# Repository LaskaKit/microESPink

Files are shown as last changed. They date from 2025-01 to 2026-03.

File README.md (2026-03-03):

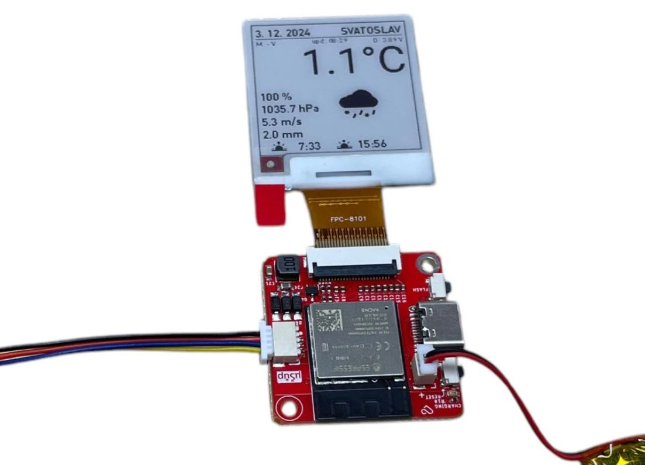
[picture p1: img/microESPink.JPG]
MicroESPink

# microESPink - micro version of ESPink - versatile and low power board with ESP32-S3 for ePaper/eInk

The MicroESPink thus complements the separate board we also offer, the [very low power and versatile ESPink](https://www.laskakit.cz/laskakit-espink-esp32-e-paper-pcb-antenna/?variantId=12419). The MicroESPink is smaller and it is also possible to connect other ePaper displays.</br>

The MicroESPink is based on the ESP32-S3 instead of the ESP32 (larger ESPink). We saved space by removing unused GPIO pins on the edge of the ESPink board, SPI usup connector etc.</br>

If you prefer a ready-to-use kit with glued ePaper, then we offer [Laskakit ESPink-Shelf-2.9 ESP32 e-Paper](https://www.laskakit.cz/laskakit-espink-shelf-2-9-esp32-e-paper/?variantId=14193, [LaskaKit ESPink-4.2 ESP32 e-Paper](https://www.laskakit.cz/laskakit-espink-42-esp32-e-paper-pcb-antenna/?variantId=13538) and [LaskaKit ESPink-Shelf-2.13 ESP32 e-Paper](https://www.laskakit.cz/laskakit-espink-shelf-213-esp32-e-paper/).</br>

The MicroESPink is based on the ESP32-S3 chip, which has support for both Wi-Fi 4 and Bluetooth 5. The board includes a 1mm pitch JST-SH battery connector. The cable for this connector can be found [in our e-shop](https://www.laskakit.cz/jst-sh-2-1-0mm-2pin-konektor-s-kabelem-10cm--oboustranny/), and the ready-made batteries with this connector are [200mAh](https://www.laskakit.cz/geb-lipol-baterie-302040-200mah-3-7v-jst-sh-2-0/) and [400mAh](https://www.laskakit.cz/geb-lipol-baterie-303048-400mah-3-7v-jst-sh-2-0/).</br>

The charging current is set by resistor R11.</br>

MicroESPink is equipped with our[universal I2C uŠup port connector](https://blog.laskakit.cz/predstavujeme-univerzalni-konektor-pro-propojeni-modulu-a-cidel-%CE%BCsup/) to which you can connect various sensors - [SHT40 (temperature, humidity)](https://www.laskakit.cz/laskakit-sht40-senzor-teploty-a-vlhkosti-vzduchu/), [BME280 (pressure, temperature, humidity)](https://www.laskakit.cz/arduino-senzor-tlaku--teploty-a-vlhkosti-bme280/), [SCD41 (CO2, temperature, humidity)](https://www.laskakit.cz/laskakit-scd41-senzor-co2--teploty-a-vlhkosti-vzduchu/), [BH1750 (lighting)](https://www.laskakit.cz/laskakit-bh1750-snimac-intenzity-osvetleni/), [APDS-9960 (gesture sensor)](https://www.laskakit.cz/laskakit-apds-9960-senzor-priblizeni-a-gest/) and many other sensors. </br>
Our I2C ushup connector is compatible with Adafruit Stemma and Qwiik from Sparkfun.</br>

The board supports the popular Živý Obraz project which greatly simplifies the use of ePaper displays to display photos, (google, outlook, apple) calendar, weather station readings, weather forecasts and much more. No need to write code, just upload the correct type of ePaper and board through the web environment and follow the procedure described [in the documentation](https://wiki.zivyobraz.eu/).</br>
[You upload the program through the webpage](https://zivyobraz.eu/?page=instalace) on this page and just select the <b>LaskaKit ESPink 3.x board</b> and the <b>correct ePaper type according to the one you ordered</b>.</br>

If you want to write your own program, go ahead :-)</br>
On our github you can find a [schematic](https://github.com/LaskaKit/microESPink/tree/main/HW) of the board and we have not forgotten the [sample codes](https://github.com/LaskaKit/microESPink/tree/main/SW), which should make programming and working with our microESPink much easier.</br>
</br>
Some technical information:</br>
The board consumption is around 16uA without connected peripherals.</br>
IO pins for I2C uŠup bus are used - SDA IO42 and SCL IO2.</br>
Power supply for external I2C sensors (uŠup), Fuel Gauge MAX17048 and ePaper is switched via GPIO pin 47. Active in HIGH.</br>
Battery status is monitored by the Fuel Gauge MAX17048 sensor connected to the same I2C bus. Its ALERT output is connected to GPIO pin 9.</br>
The MicroESPink has two pre-made solder bridges to adjust the driver settings on the board - see the schematic for a description of the settings for the ePapers.</br>
Both battery charging and board programming is done via USB-C.</br>
The board needs to be switched to recording mode, this is done by the following procedure: connect USB-C, press and hold the FLASH button, press and release the RESET button, then release the FLASH button.</br>
</br>
## The microESPink is available on https://www.laskakit.cz/laskakit-microespink-esp32-s3-mini-e-paper/?variantId=17078

| Display | JP1 | JP2 |
| --- | --- | --- |
| GDEWO0154T8D | ON | ON |
| GDEY0154D67 | OFF | ON |
| GDEY0154Z90 | OFF | OFF |
| GDEY0213B74 | OFF | ON |
| GDEW0213TS5D | ON | ON |
| GDEY027T91 | OFF | ON |
| GDEWO029TS5D | ON | OFF |
| GDEY029T94 | OFF | ON |
| GDEYO29F51H | OFF | OFF |
| GDEY029T71H | OFF | OFF |
| GDEY042T81 | OFF | ON |
| GDEQ042Z21 | ON | OFF |
| GDEY042Z798 | OFF | OFF |
| GDEQ0426T82 | OFF | ON |
| GDEPO565D90 | ON | OFF |
| GDEQ0583T31 | ON | OFF |
| GDEQ0583Z31 | ON | OFF |
| GDEYO7ST7 | ON | OFF |
| GDEY075Z08 | ON | OFF |
| GDEM102T91 | OFF | ON |
| GDEM102Z91 | ON | OFF |
| GDEM1085T51 | OFF | OFF |
| GDEY116Z91 | OFF | ON |
| GDEY116T91 | OFF | ON |
| GDEY116F51 | OFF | OFF |
| GDEM133Z91 | OFF | ON |
| GDEM133T91 | OFF | ON |

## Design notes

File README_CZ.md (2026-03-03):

MicroESPink

# microESPink - mikro verze desky ESPink - univerzální a velmi úsporná deska s ESP32-S3 pro ePaper

MicroESPink tak doplňuje samostatnou desku, kterou máme také v nabídce [velmi úspornou a univerzální ESPink](https://www.laskakit.cz/laskakit-espink-esp32-e-paper-pcb-antenna/?variantId=12419). MicroESPink je menší a je také možné připojit jiné ePaper displeje. </br>

MicroESPink je založen na ESP32-S3 namísto ESP32 (větší ESPink). Místo jsme ušetřili odebráním nepoužitých GPIO pinů na okraji desky ESPink, SPI uŠup konektoru atp.</br>

Pokud preferuješ už hotový kit s přilepeným ePaper, pak máme v nabídce [Laskakit ESPink-Shelf-2.9 ESP32 e-Paper](https://www.laskakit.cz/laskakit-espink-shelf-2-9-esp32-e-paper/?variantId=14193), [LaskaKit ESPink-4.2 ESP32 e-Paper](https://www.laskakit.cz/laskakit-espink-42-esp32-e-paper-pcb-antenna/?variantId=13538) a [LaskaKit ESPink-Shelf-2.13 ESP32 e-Paper](https://www.laskakit.cz/laskakit-espink-shelf-213-esp32-e-paper/).</br>

MicroESPink je založený na čipu ESP32-S3, který má podporu jak Wi-Fi 4, tak i Bluetooth 5.
Deska obsahuje konektor pro baterii JST-SH s roztečí 1mm. Kabel pro tento konektor [najdeš v našem e-shopu](https://www.laskakit.cz/jst-sh-2-1-0mm-2pin-konektor-s-kabelem-10cm--oboustranny/), už hotové baterie s tímto konektorem jsou pak [200mAh](https://www.laskakit.cz/geb-lipol-baterie-302040-200mah-3-7v-jst-sh-2-0/) a [400mAh](https://www.laskakit.cz/geb-lipol-baterie-303048-400mah-3-7v-jst-sh-2-0/).

Nabíjecí proud je nastaven rezistorem R11.

MicroESPink má osazený [náš univerzální I2C uŠup konektor](https://blog.laskakit.cz/predstavujeme-univerzalni-konektor-pro-propojeni-modulu-a-cidel-%CE%BCsup/) ke kterým můžeš připojit nejrůznější čidla - [SHT40 (teplota, vlhkost)](https://www.laskakit.cz/laskakit-sht40-senzor-teploty-a-vlhkosti-vzduchu/), [BME280 (tlak, teplota, vlhkost)](https://www.laskakit.cz/arduino-senzor-tlaku--teploty-a-vlhkosti-bme280/), [SCD41 (CO2, teplota, vlhkost)](https://www.laskakit.cz/laskakit-scd41-senzor-co2--teploty-a-vlhkosti-vzduchu/), [BH1750 (osvětlení)](https://www.laskakit.cz/laskakit-bh1750-snimac-intenzity-osvetleni/), [APDS-9960 (senzor gest)](https://www.laskakit.cz/laskakit-apds-9960-senzor-priblizeni-a-gest/) a spoustu další senzorů. Náš I2C uŠup konektor je kompatibilní s Adafruit Stemma a Qwiik od Sparkfun.</br>
</br>
Deska podporuje populární projekt Živý Obraz, který výrazně zjednodušuje použití ePaper displeje k zobrazení fotografií, (google, outlook, apple) kalendáře, kurzů, hodnot z meteostanic, předpovědi počasí a mnoho dalšího. Není nutné psát kód, stačí nahrát správný typ ePaper a desky skrze webové prostředí a dodržet postup popsaný v [dokumentaci](https://wiki.zivyobraz.eu/).</br>
Program nahraješ [přes webové prostředí na této stránce](https://zivyobraz.eu/?page=instalace) a stačí zvolit desku <b>LaskaKit ESPink 3.x</b> a <b>správný typ ePaperu podle toho, který sis objednal</b>. </br>
</br>
Pokud si chceš napsat vlastní program, tak do toho :-)</br>
Na našem github máš [schéma desky](https://github.com/LaskaKit/microESPink/tree/main/HW) a nezapomněli jsme ani na [vzorové kódy](https://github.com/LaskaKit/microESPink/tree/main/SW), které by ti značně měly usnadnit programování a práci s naším microESPink. </br>
</br>
Pár technických informací:</br>
Spotřeba desky je okolo 16uA bez připojených periférií.</br>
IO piny pro I2C sběrnici jsou použity - SDA IO42 a SCL IO2.</br>
Napájení pro externí I2C čidla (uŠup), Fuel Gauge MAX17048 a ePaper je spínán přes GPIO pin 47. Aktivní v HIGH.</br>
Stav baterie je monitorován Fuel Gauge senzorem MAX17048 připojeným na stejnou I2C sběrnici. Jeho ALERT výstup je připojen k GPIO pin 9.</br>
MicroESPink má předpřipravené dva pájecí mosty, kterými se upravuje nastavení driveru na desce - popis nastavení pro ePapery najdeš ve schématu. </br>
Skrze USB-C se nabíjí jak baterie, tak probíhá i programování desky. </br>
Desku je nutné přepnout do režimu nahrávání, to provedeš tímto postupem: připojíš USB-C, zmáčkneš tlačítko FLASH a držíš, zmáčkneš a uvolníš tlačítko RESET a poté uvolníš tlačítko FLASH. </br>

## MicroESPink je k zakoupení na našem e-shopu [https://www.laskakit.cz/laskakit-microespink-esp32-s3-mini-e-paper/?variantId=17078](https://www.laskakit.cz/laskakit-microespink-esp32-s3-mini-e-paper/?variantId=17078)

| Display | JP1 | JP2 |
| --- | --- | --- |
| GDEWO0154T8D | ON | ON |
| GDEY0154D67 | OFF | ON |
| GDEY0154Z90 | OFF | OFF |
| GDEY0213B74 | OFF | ON |
| GDEW0213TS5D | ON | ON |
| GDEY027T91 | OFF | ON |
| GDEWO029TS5D | ON | OFF |
| GDEY029T94 | OFF | ON |
| GDEYO29F51H | OFF | OFF |
| GDEY029T71H | OFF | OFF |
| GDEY042T81 | OFF | ON |
| GDEQ042Z21 | ON | OFF |
| GDEY042Z798 | OFF | OFF |
| GDEQ0426T82 | OFF | ON |
| GDEPO565D90 | ON | OFF |
| GDEQ0583T31 | ON | OFF |
| GDEQ0583Z31 | ON | OFF |
| GDEYO7ST7 | ON | OFF |
| GDEY075Z08 | ON | OFF |
| GDEM102T91 | OFF | ON |
| GDEM102Z91 | ON | OFF |
| GDEM1085T51 | OFF | OFF |
| GDEY116Z91 | OFF | ON |
| GDEY116T91 | OFF | ON |
| GDEY116F51 | OFF | OFF |
| GDEM133Z91 | OFF | ON |
| GDEM133T91 | OFF | ON |

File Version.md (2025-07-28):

### Version 1.2
- Fuel Gauge replaced by ESP ADC
- Epaper BUSY pin changed from IO36 to IO38
- Epaper CS2 pin changed from IO35 to IO18
#### Version 1.1
- Charding current changed to 0.26A
- LDO hcanged to RT9080
#### Version 1.0
- Initial | Počáteční

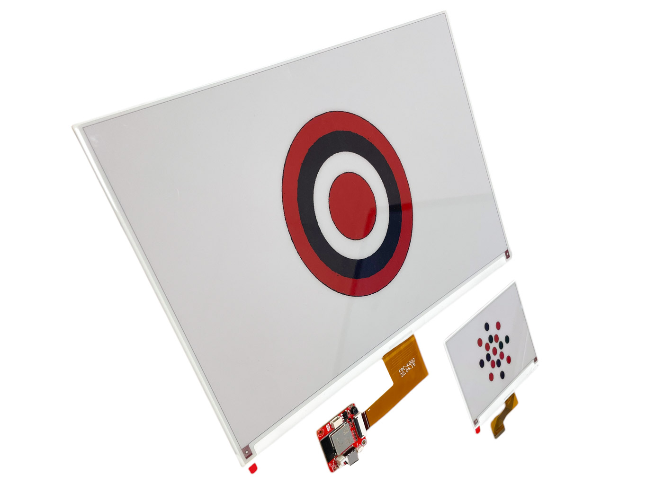
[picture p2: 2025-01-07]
img/LaskaKit-microespink-esp32-s3-mini-e-paper-6.jpg

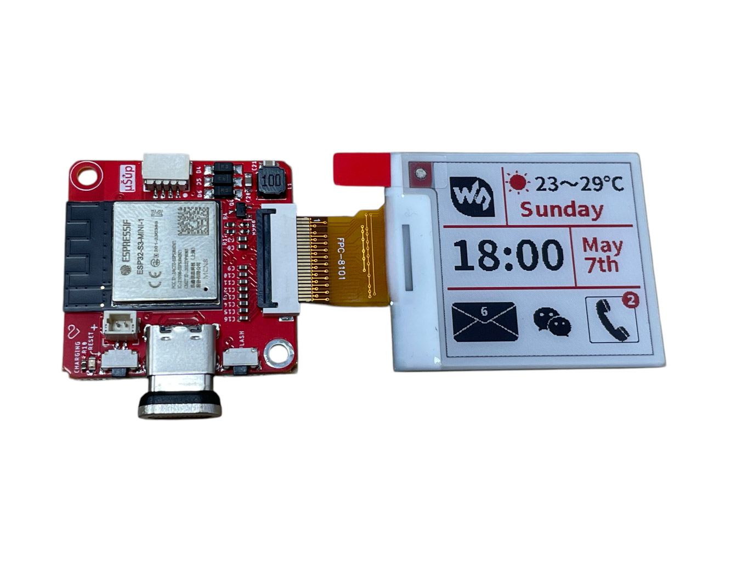
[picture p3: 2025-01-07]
img/LaskaKit-microespink-esp32-s3-mini-e-paper-5.jpg

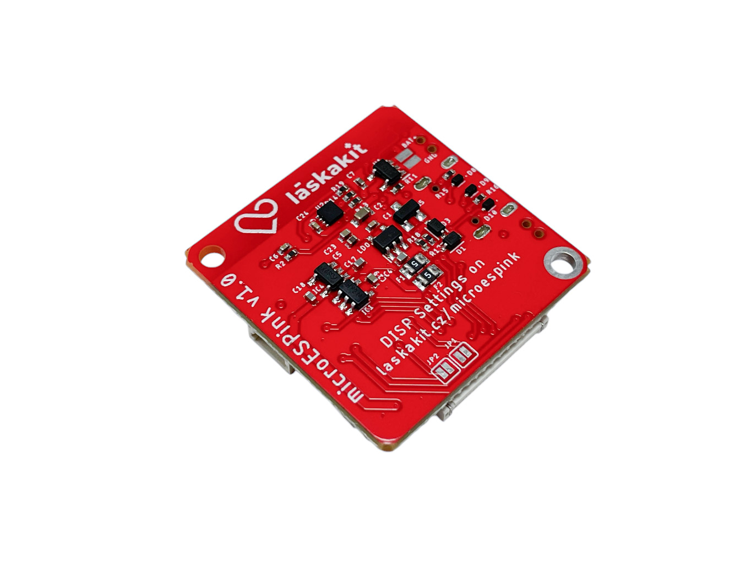
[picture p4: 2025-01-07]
img/LaskaKit-microespink-esp32-s3-mini-e-paper-3.jpg

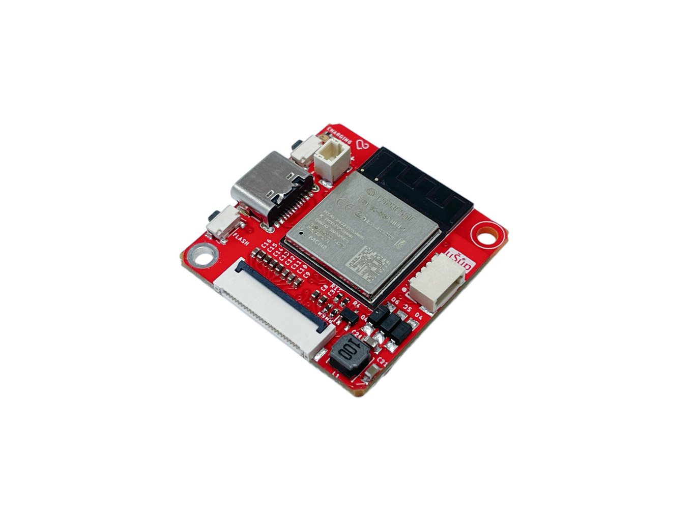
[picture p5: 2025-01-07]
img/LaskaKit-microespink-esp32-s3-mini-e-paper-1.jpg

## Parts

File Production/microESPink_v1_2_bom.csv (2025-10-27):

Comment | Designator | Footprint | LCSC Part #
0.47R | R9 | R0402 | C723356
1M | R4 | R0402
1uF/50V | C9 C10 C11 C16 | C0402
1x2P SH | J1 | 1X02_1MM_RA_VERT | C7430451
2.55R | R12 | R0402 | C477655
3.3k | R10 | R0402
4.7uF/25V | C3 C8 C12 C13 C14 C15 | C0402
4.7uF/25V | C20 | C0603
10k | R8 | R0402
10uF/25V | C21 | C0603
10uH/1A | L1 | SMNR4020 | C497803
47uF | C19 | C0402 | C178330
100nF | C1 | C0201 | C2846674
AFC24-S24FIC-00 | J5 | FFC2B2824G | C262292
EN button | FLASH RESET | 1TS003B16003500A | C255808
ESP32-S3-MINI-1-N8 | IC2 | ESP32S3MINI1N8
JST-SH-4P | J2 | 1X04_1MM_RA_VERT | C7430453
MBR0530 | D4 D5 D6 | SOD123-F
RED | CHARGING | CHIP-LED0603 | C241893
Si1308EDL | Q4 | SOT65P210X110-3N | C469327
USB-C_GT-USB-7010B | J4 | G-SWITCH_GT-USB-7010B | C2837092
1.3M | R21 | R0402
1M | R20 | R0402
3k3 | R11 | R0402
4.7k | R14 R19 | R0402
5.1k | R15 R16 | R0402
10k | R1 R2 R17 | R0402
10uF/10V | C4 C5 C7 C17 C18 | C0402
47uF | C2 C22 C23 | C0603 | C178330
100k | R18 | R0402
100nF | C6 C24 | C0402
AO3401 | Q5 | SOT23
BAT60B | D1 D3 | SOD323-R
LESD5D5.0CT1G | D8 D9 D10 | LESD5D50CT1G
RT9080-33GJ5 | IC4 LDO | SOT94P280X100-5N
TP4054 | U1 | SOT-23-5 | C32574

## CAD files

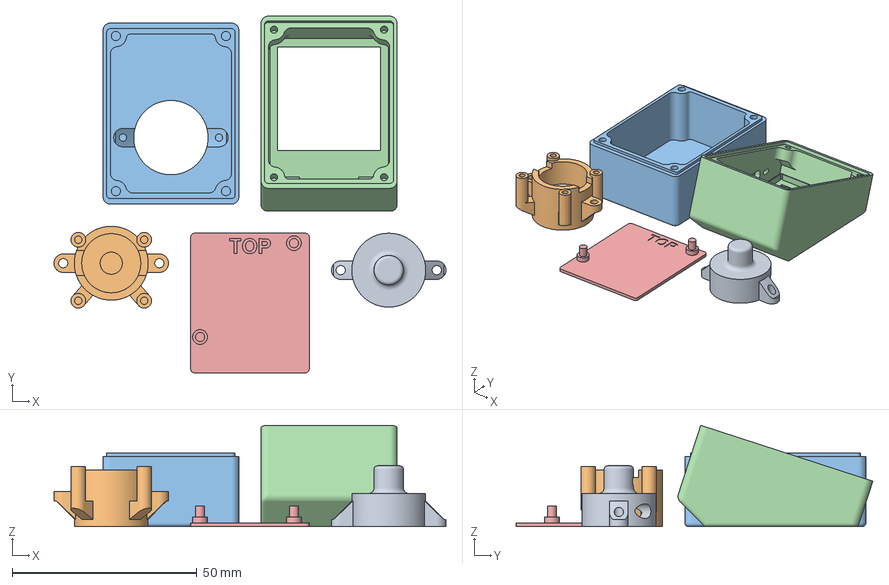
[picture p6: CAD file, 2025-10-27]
3D/Case-154/LaskaKit-Live-1-54.3mf
106.1 x 96.6 x 27.4 mm
temp_Holder v6
CO2_Holder v12
back
front
backplate v16

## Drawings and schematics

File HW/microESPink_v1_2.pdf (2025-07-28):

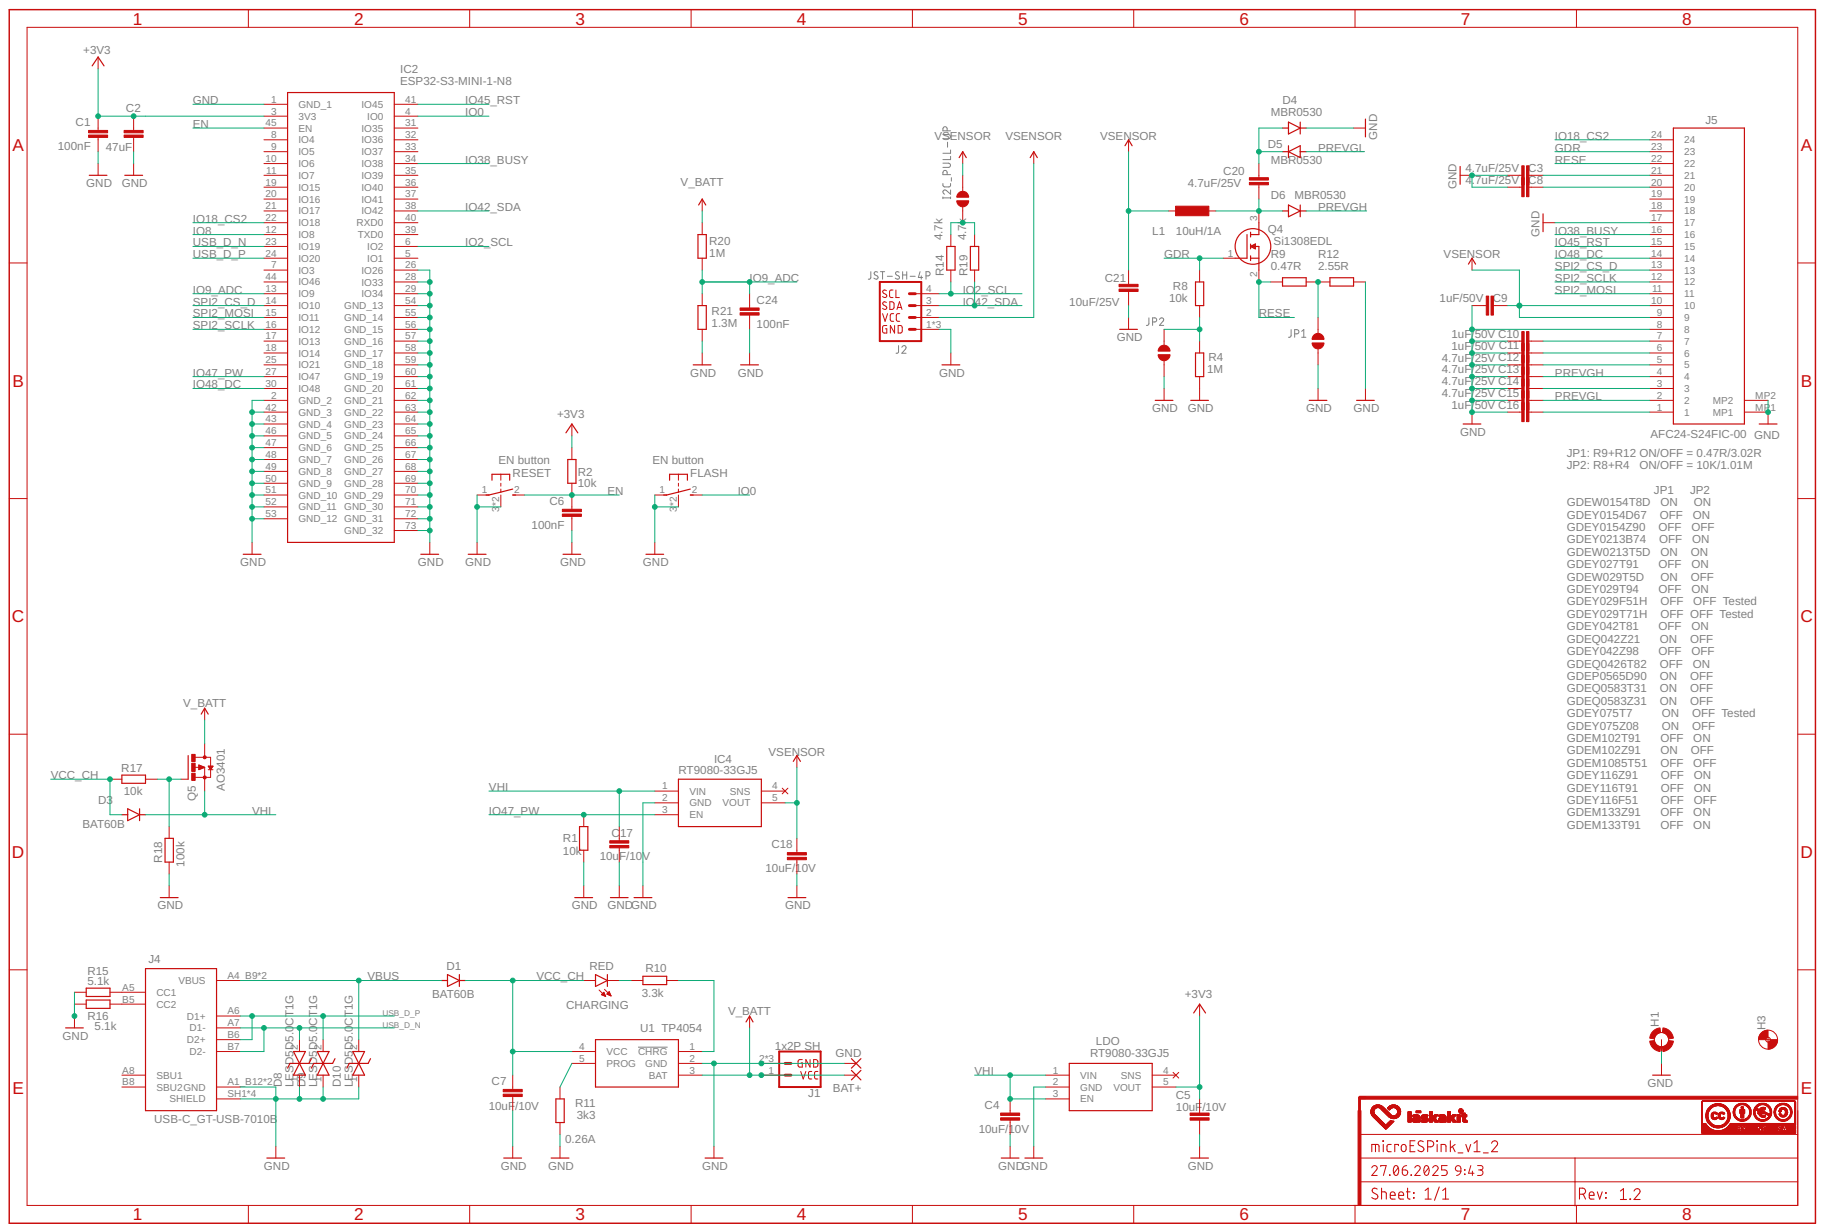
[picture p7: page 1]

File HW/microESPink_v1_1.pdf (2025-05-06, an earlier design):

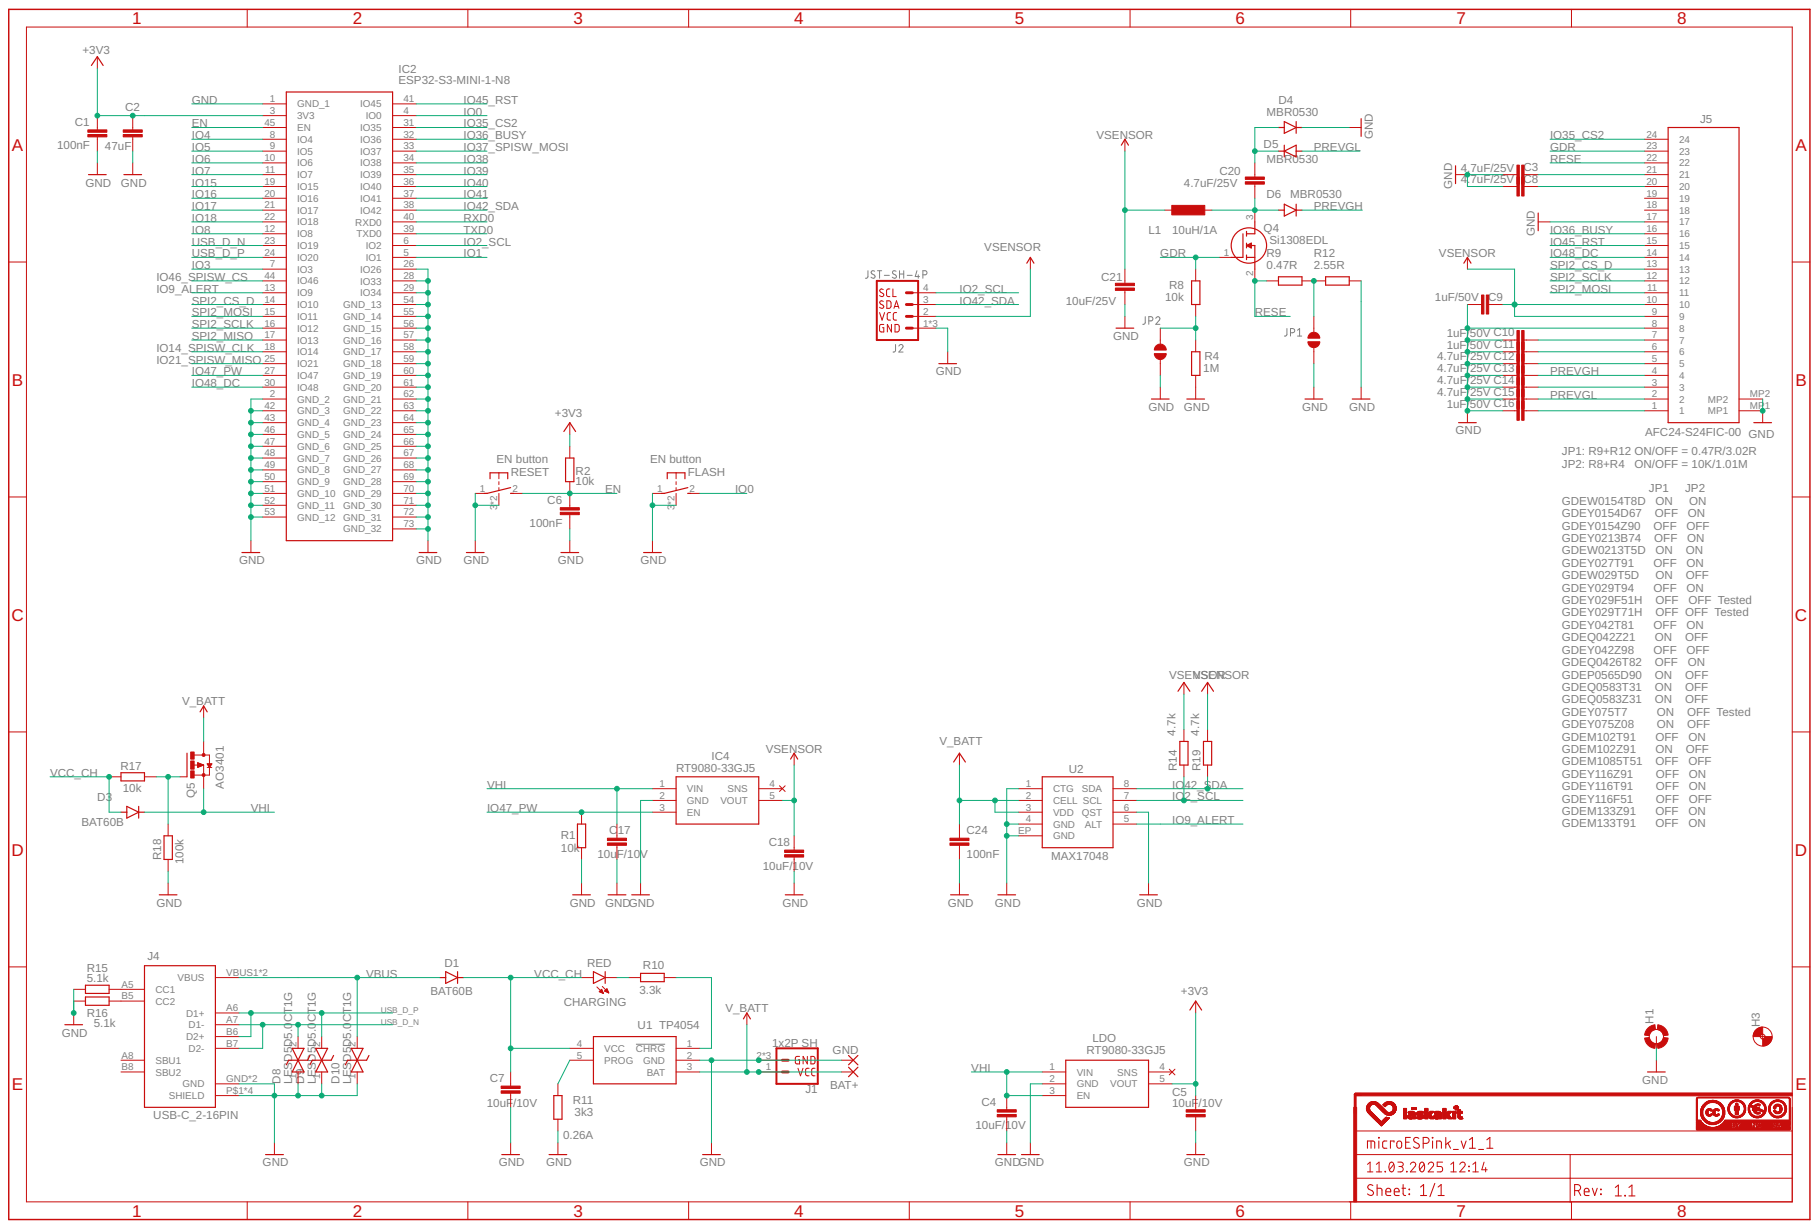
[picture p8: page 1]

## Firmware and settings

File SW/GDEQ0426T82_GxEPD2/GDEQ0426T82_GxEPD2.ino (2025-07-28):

 /* Display test for Good Display GDEQ0426T82
 * example from GxEPD2 library is used
 * 
 * Board:   LaskaKit microESPink ESP32-S3   https://www.laskakit.cz/laskakit-microespink-esp32-s3-mini-e-paper/
 * Display: Good Display GDEQ0426T82        https://www.laskakit.cz/good-display-gdeq0426t82-4-26--800x480-epaper-displej-grayscale/  
 * 
 * Email:podpora@laskakit.cz
 * Web:laskakit.cz
 */

// Display Library example for SPI e-paper panels from Dalian Good Display.
// Requires Adafruit_GFX and https://github.com/ZinggJM/GxEPD2 Author: Jean-Marc Zingg
// Display Library based on Demo Example from Good Display: http://www.e-paper-display.com/download_list/downloadcategoryid=34&isMode=false.html

#define ENABLE_GxEPD2_GFX 0

#include <GxEPD2_BW.h>
#include <Fonts/FreeMonoBold9pt7b.h>
#include "bitmaps/Bitmaps1304x984.h" // 12.48" b/w

#define SLEEP_SEC 15         // Measurement interval (seconds)

//MOSI/SDI    11
//CLK/SCK     12
//SS/CS       10
#define DC    48 
#define RST   45  
#define BUSY  38 
#define POWER 47

GxEPD2_BW<GxEPD2_426_GDEQ0426T82, GxEPD2_426_GDEQ0426T82::HEIGHT> display(GxEPD2_426_GDEQ0426T82(SS, DC, RST, BUSY)); // GDEQ0426T82 480x800, SSD1677 (P426010-MF1-A)

void setup()
{
  Serial.begin(115200);
  Serial.println();
  Serial.println("setup");
  delay(100);

// turn on power to display
  pinMode(POWER, OUTPUT);
  digitalWrite(POWER, HIGH);   // turn the Display on (HIGH is the voltage level)
  Serial.println("Display power ON");
  delay(1000);   
  
  display.init(); // inicializace

  display.fillScreen(GxEPD_WHITE);
  delay(1000);
  // first update should be full refresh
  helloWorld();
  delay(1000);
  // partial refresh mode can be used to full screen,
  // effective if display panel hasFastPartialUpdate
  helloFullScreenPartialMode();
  delay(1000);
  //stripeTest(); return; // GDEH029Z13 issue
  helloArduino();
  delay(1000);
  helloEpaper();
  delay(1000);
  //helloValue(123.9, 1);
  //delay(1000);
  showFont("FreeMonoBold9pt7b", &FreeMonoBold9pt7b);
  delay(1000);
  if (display.epd2.WIDTH < 104)
  {
    showFont("glcdfont", 0);
    delay(1000);
  }
  drawBitmaps();

  if (display.epd2.panel == GxEPD2::ACeP565)
  {
    //draw7colorlines();
    //delay(2000);
    draw7colors();
    delay(4000);
  }

  if (display.epd2.hasPartialUpdate)
  {
    showPartialUpdate();
    delay(1000);
  } // else // on GDEW0154Z04 only full update available, doesn't look nice
  //drawCornerTest();
  //showBox(16, 16, 48, 32, false);
  //showBox(16, 56, 48, 32, true);
  display.powerOff();
  deepSleepTest();

  drawBitmaps1304x984();
  display.powerOff();

  Serial.println("setup done");

}


void loop()
{
}

// note for partial update window and setPartialWindow() method:
// partial update window size and position is on byte boundary in physical x direction
// the size is increased in setPartialWindow() if x or w are not multiple of 8 for even rotation, y or h for odd rotation
// see also comment in GxEPD2_BW.h, GxEPD2_3C.h or GxEPD2_GFX.h for method setPartialWindow()

const char HelloWorld[] = "Hello World!";
const char HelloArduino[] = "Hello Arduino!";
const char HelloEpaper[] = "Hello E-Paper!";

void helloWorld()
{
  //Serial.println("helloWorld");
  display.setRotation(1);
  display.setFont(&FreeMonoBold9pt7b);
  if (display.epd2.WIDTH < 104) display.setFont(0);
  display.setTextColor(GxEPD_BLACK);
  int16_t tbx, tby; uint16_t tbw, tbh;
  display.getTextBounds(HelloWorld, 0, 0, &tbx, &tby, &tbw, &tbh);
  // center bounding box by transposition of origin:
  uint16_t x = ((display.width() - tbw) / 2) - tbx;
  uint16_t y = ((display.height() - tbh) / 2) - tby;
  display.setFullWindow();
  display.firstPage();
  do
  {
    display.fillScreen(GxEPD_WHITE);
    display.setCursor(x, y);
    display.print(HelloWorld);
  }
  while (display.nextPage());
  //Serial.println("helloWorld done");
}

void helloWorldForDummies()
{
  //Serial.println("helloWorld");
  const char text[] = "Hello World!";
  // most e-papers have width < height (portrait) as native orientation, especially the small ones
  // in GxEPD2 rotation 0 is used for native orientation (most TFT libraries use 0 fix for portrait orientation)
  // set rotation to 1 (rotate right 90 degrees) to have enough space on small displays (landscape)
  display.setRotation(1);
  // select a suitable font in Adafruit_GFX
  display.setFont(&FreeMonoBold9pt7b);
  // on e-papers black on white is more pleasant to read
  display.setTextColor(GxEPD_BLACK);
  // Adafruit_GFX has a handy method getTextBounds() to determine the boundary box for a text for the actual font
  int16_t tbx, tby; uint16_t tbw, tbh; // boundary box window
  display.getTextBounds(text, 0, 0, &tbx, &tby, &tbw, &tbh); // it works for origin 0, 0, fortunately (negative tby!)
  // center bounding box by transposition of origin:
  uint16_t x = ((display.width() - tbw) / 2) - tbx;
  uint16_t y = ((display.height() - tbh) / 2) - tby;
  // full window mode is the initial mode, set it anyway
  display.setFullWindow();
  // here we use paged drawing, even if the processor has enough RAM for full buffer
  // so this can be used with any supported processor board.
  // the cost in code overhead and execution time penalty is marginal
  // tell the graphics class to use paged drawing mode
  display.firstPage();
  do
  {
    // this part of code is executed multiple times, as many as needed,
    // in case of full buffer it is executed once
    // IMPORTANT: each iteration needs to draw the same, to avoid strange effects
    // use a copy of values that might change, don't read e.g. from analog or pins in the loop!
    display.fillScreen(GxEPD_WHITE); // set the background to white (fill the buffer with value for white)
    display.setCursor(x, y); // set the postition to start printing text
    display.print(text); // print some text
    // end of part executed multiple times
  }
  // tell the graphics class to transfer the buffer content (page) to the controller buffer
  // the graphics class will command the controller to refresh to the screen when the last page has been transferred
  // returns true if more pages need be drawn and transferred
  // returns false if the last page has been transferred and the screen refreshed for panels without fast partial update
  // returns false for panels with fast partial update when the controller buffer has been written once more, to make the differential buffers equal
  // (for full buffered with fast partial update the (full) buffer is just transferred again, and false returned)
  while (display.nextPage());
  //Serial.println("helloWorld done");
}

void helloFullScreenPartialMode()
{
  //Serial.println("helloFullScreenPartialMode");
  const char fullscreen[] = "full screen update";
  const char fpm[] = "fast partial mode";
  const char spm[] = "slow partial mode";
  const char npm[] = "no partial mode";
  display.setPartialWindow(0, 0, display.width(), display.height());
  display.setRotation(1);
  display.setFont(&FreeMonoBold9pt7b);
  if (display.epd2.WIDTH < 104) display.setFont(0);
  display.setTextColor(GxEPD_BLACK);
  const char* updatemode;
  if (display.epd2.hasFastPartialUpdate)
  {
    updatemode = fpm;
  }
  else if (display.epd2.hasPartialUpdate)
  {
    updatemode = spm;
  }
  else
  {
    updatemode = npm;
  }
  // do this outside of the loop
  int16_t tbx, tby; uint16_t tbw, tbh;
  // center update text
  display.getTextBounds(fullscreen, 0, 0, &tbx, &tby, &tbw, &tbh);
  uint16_t utx = ((display.width() - tbw) / 2) - tbx;
  uint16_t uty = ((display.height() / 4) - tbh / 2) - tby;
  // center update mode
  display.getTextBounds(updatemode, 0, 0, &tbx, &tby, &tbw, &tbh);
  uint16_t umx = ((display.width() - tbw) / 2) - tbx;
  uint16_t umy = ((display.height() * 3 / 4) - tbh / 2) - tby;
  // center HelloWorld
  display.getTextBounds(HelloWorld, 0, 0, &tbx, &tby, &tbw, &tbh);
  uint16_t hwx = ((display.width() - tbw) / 2) - tbx;
  uint16_t hwy = ((display.height() - tbh) / 2) - tby;
  display.firstPage();
  do
  {
    display.fillScreen(GxEPD_WHITE);
    display.setCursor(hwx, hwy);
    display.print(HelloWorld);
    display.setCursor(utx, uty);
    display.print(fullscreen);
    display.setCursor(umx, umy);
    display.print(updatemode);
  }
  while (display.nextPage());
  //Serial.println("helloFullScreenPartialMode done");
}

void helloArduino()
{
  //Serial.println("helloArduino");
  display.setRotation(1);
  display.setFont(&FreeMonoBold9pt7b);
  if (display.epd2.WIDTH < 104) display.setFont(0);
  display.setTextColor(display.epd2.hasColor ? GxEPD_RED : GxEPD_BLACK);
  int16_t tbx, tby; uint16_t tbw, tbh;
  // align with centered HelloWorld
  display.getTextBounds(HelloWorld, 0, 0, &tbx, &tby, &tbw, &tbh);
  uint16_t x = ((display.width() - tbw) / 2) - tbx;
  // height might be different
  display.getTextBounds(HelloArduino, 0, 0, &tbx, &tby, &tbw, &tbh);
  uint16_t y = ((display.height() / 4) - tbh / 2) - tby; // y is base line!
  // make the window big enough to cover (overwrite) descenders of previous text
  uint16_t wh = FreeMonoBold9pt7b.yAdvance;
  uint16_t wy = (display.height() / 4) - wh / 2;
  display.setPartialWindow(0, wy, display.width(), wh);
  display.firstPage();
  do
  {
    display.fillScreen(GxEPD_WHITE);
    //display.drawRect(x, y - tbh, tbw, tbh, GxEPD_BLACK);
    display.setCursor(x, y);
    display.print(HelloArduino);
  }
  while (display.nextPage());
  delay(1000);
  //Serial.println("helloArduino done");
}

void helloEpaper()
{
  //Serial.println("helloEpaper");
  display.setRotation(1);
  display.setFont(&FreeMonoBold9pt7b);
  if (display.epd2.WIDTH < 104) display.setFont(0);
  display.setTextColor(display.epd2.hasColor ? GxEPD_RED : GxEPD_BLACK);
  int16_t tbx, tby; uint16_t tbw, tbh;
  // align with centered HelloWorld
  display.getTextBounds(HelloWorld, 0, 0, &tbx, &tby, &tbw, &tbh);
  uint16_t x = ((display.width() - tbw) / 2) - tbx;
  // height might be different
  display.getTextBounds(HelloEpaper, 0, 0, &tbx, &tby, &tbw, &tbh);
  uint16_t y = ((display.height() * 3 / 4) - tbh / 2) - tby; // y is base line!
  // make the window big enough to cover (overwrite) descenders of previous text
  uint16_t wh = FreeMonoBold9pt7b.yAdvance;
  uint16_t wy = (display.height() * 3 / 4) - wh / 2;
  display.setPartialWindow(0, wy, display.width(), wh);
  display.firstPage();
  do
  {
    display.fillScreen(GxEPD_WHITE);
    display.setCursor(x, y);
    display.print(HelloEpaper);
  }
  while (display.nextPage());
  //Serial.println("helloEpaper done");
}

// test partial window issue on GDEW0213Z19 and GDEH029Z13
void stripeTest()
{
  helloStripe(104);
  delay(2000);
  helloStripe(96);
}

const char HelloStripe[] = "Hello Stripe!";

void helloStripe(uint16_t pw_xe) // end of partial window in physcal x direction
{
  //Serial.print("HelloStripe("); Serial.print(pw_xe); Serial.println(")");
  display.setRotation(3);
  display.setFont(&FreeMonoBold9pt7b);
  display.setTextColor(display.epd2.hasColor ? GxEPD_RED : GxEPD_BLACK);
  int16_t tbx, tby; uint16_t tbw, tbh;
  display.getTextBounds(HelloStripe, 0, 0, &tbx, &tby, &tbw, &tbh);
  uint16_t wh = FreeMonoBold9pt7b.yAdvance;
  uint16_t wy = pw_xe - wh;
  uint16_t x = ((display.width() - tbw) / 2) - tbx;
  uint16_t y = wy - tby;
  display.setPartialWindow(0, wy, display.width(), wh);
  display.firstPage();
  do
  {
    display.fillScreen(GxEPD_WHITE);
    display.setCursor(x, y);
    display.print(HelloStripe);
  }
  while (display.nextPage());
  //Serial.println("HelloStripe done");
}

#if defined(ESP8266) || defined(ESP32)
#include <StreamString.h>
#define PrintString StreamString
#else
class PrintString : public Print, public String
{
  public:
    size_t write(uint8_t data) override
    {
      return concat(char(data));
    };
};
#endif

void helloValue(double v, int digits)
{
  //Serial.println("helloValue");
  display.setRotation(1);
  display.setFont(&FreeMonoBold9pt7b);
  display.setTextColor(display.epd2.hasColor ? GxEPD_RED : GxEPD_BLACK);
  PrintString valueString;
  valueString.print(v, digits);
  int16_t tbx, tby; uint16_t tbw, tbh;
  display.getTextBounds(valueString, 0, 0, &tbx, &tby, &tbw, &tbh);
  uint16_t x = ((display.width() - tbw) / 2) - tbx;
  uint16_t y = ((display.height() * 3 / 4) - tbh / 2) - tby; // y is base line!
  // show what happens, if we use the bounding box for partial window
  uint16_t wx = (display.width() - tbw) / 2;
  uint16_t wy = ((display.height() * 3 / 4) - tbh / 2);
  display.setPartialWindow(wx, wy, tbw, tbh);
  display.firstPage();
  do
  {
    display.fillScreen(GxEPD_WHITE);
    display.setCursor(x, y);
    display.print(valueString);
  }
  while (display.nextPage());
  delay(2000);
  // make the partial window big enough to cover the previous text
  uint16_t ww = tbw; // remember window width
  display.getTextBounds(HelloEpaper, 0, 0, &tbx, &tby, &tbw, &tbh);
  // adjust, because HelloEpaper was aligned, not centered (could calculate this to be precise)
  ww = max(ww, uint16_t(tbw + 12)); // 12 seems ok
  wx = (display.width() - tbw) / 2;
  // make the window big enough to cover (overwrite) descenders of previous text
  uint16_t wh = FreeMonoBold9pt7b.yAdvance;
  wy = (display.height() * 3 / 4) - wh / 2;
  display.setPartialWindow(wx, wy, ww, wh);
  // alternately use the whole width for partial window
  //display.setPartialWindow(0, wy, display.width(), wh);
  display.firstPage();
  do
  {
    display.fillScreen(GxEPD_WHITE);
    display.setCursor(x, y);
    display.print(valueString);
  }
  while (display.nextPage());
  //Serial.println("helloValue done");
}

void deepSleepTest()
{
  //Serial.println("deepSleepTest");
  const char hibernating[] = "hibernating ...";
  const char wokeup[] = "woke up";
  const char from[] = "from deep sleep";
  const char again[] = "again";
  display.setRotation(1);
  display.setFont(&FreeMonoBold9pt7b);
  if (display.epd2.WIDTH < 104) display.setFont(0);
  display.setTextColor(GxEPD_BLACK);
  int16_t tbx, tby; uint16_t tbw, tbh;
  // center text
  display.getTextBounds(hibernating, 0, 0, &tbx, &tby, &tbw, &tbh);
  uint16_t x = ((display.width() - tbw) / 2) - tbx;
  uint16_t y = ((display.height() - tbh) / 2) - tby;
  display.setFullWindow();
  display.firstPage();
  do
  {
    display.fillScreen(GxEPD_WHITE);
    display.setCursor(x, y);
    display.print(hibernating);
  }
  while (display.nextPage());
  display.hibernate();
  delay(5000);
  display.getTextBounds(wokeup, 0, 0, &tbx, &tby, &tbw, &tbh);
  uint16_t wx = (display.width() - tbw) / 2;
  uint16_t wy = ((display.height() / 3) - tbh / 2) - tby; // y is base line!
  display.getTextBounds(from, 0, 0, &tbx, &tby, &tbw, &tbh);
  uint16_t fx = (display.width() - tbw) / 2;
  uint16_t fy = ((display.height() * 2 / 3) - tbh / 2) - tby; // y is base line!
  display.firstPage();
  do
  {
    display.fillScreen(GxEPD_WHITE);
    display.setCursor(wx, wy);
    display.print(wokeup);
    display.setCursor(fx, fy);
    display.print(from);
  }
  while (display.nextPage());
  delay(5000);
  display.getTextBounds(hibernating, 0, 0, &tbx, &tby, &tbw, &tbh);
  uint16_t hx = (display.width() - tbw) / 2;
  uint16_t hy = ((display.height() / 3) - tbh / 2) - tby; // y is base line!
  display.getTextBounds(again, 0, 0, &tbx, &tby, &tbw, &tbh);
  uint16_t ax = (display.width() - tbw) / 2;
  uint16_t ay = ((display.height() * 2 / 3) - tbh / 2) - tby; // y is base line!
  display.firstPage();
  do
  {
    display.fillScreen(GxEPD_WHITE);
    display.setCursor(hx, hy);
    display.print(hibernating);
    display.setCursor(ax, ay);
    display.print(again);
  }
  while (display.nextPage());
  display.hibernate();
  //Serial.println("deepSleepTest done");
}

void showBox(uint16_t x, uint16_t y, uint16_t w, uint16_t h, bool partial)
{
  //Serial.println("showBox");
  display.setRotation(1);
  if (partial)
  {
    display.setPartialWindow(x, y, w, h);
  }
  else
  {
    display.setFullWindow();
  }
  display.firstPage();
  do
  {
    display.fillScreen(GxEPD_WHITE);
    display.fillRect(x, y, w, h, GxEPD_BLACK);
  }
  while (display.nextPage());
  //Serial.println("showBox done");
}

void drawCornerTest()
{
  display.setFullWindow();
  display.setFont(&FreeMonoBold9pt7b);
  display.setTextColor(GxEPD_BLACK);
  for (uint16_t r = 0; r <= 4; r++)
  {
    display.setRotation(r);
    display.firstPage();
    do
    {
      display.fillScreen(GxEPD_WHITE);
      display.fillRect(0, 0, 8, 8, GxEPD_BLACK);
      display.fillRect(display.width() - 18, 0, 16, 16, GxEPD_BLACK);
      display.fillRect(display.width() - 25, display.height() - 25, 24, 24, GxEPD_BLACK);
      display.fillRect(0, display.height() - 33, 32, 32, GxEPD_BLACK);
      display.setCursor(display.width() / 2, display.height() / 2);
      display.print(display.getRotation());
    }
    while (display.nextPage());
    delay(2000);
  }
}

void showFont(const char name[], const GFXfont* f)
{
  display.setFullWindow();
  display.setRotation(0);
  display.setTextColor(GxEPD_BLACK);
  display.firstPage();
  do
  {
    drawFont(name, f);
  }
  while (display.nextPage());
}

void drawFont(const char name[], const GFXfont* f)
{
  //display.setRotation(0);
  display.fillScreen(GxEPD_WHITE);
  display.setTextColor(GxEPD_BLACK);
  display.setFont(f);
  display.setCursor(0, 0);
  display.println();
  display.println(name);
  display.println(" !\"#$%&'()*+,-./");
  display.println("0123456789:;<=>?");
  display.println("@ABCDEFGHIJKLMNO");
  display.println("PQRSTUVWXYZ[\\]^_");
  if (display.epd2.hasColor)
  {
    display.setTextColor(GxEPD_RED);
  }
  display.println("`abcdefghijklmno");
  display.println("pqrstuvwxyz{|}~ ");
}

// note for partial update window and setPartialWindow() method:
// partial update window size and position is on byte boundary in physical x direction
// the size is increased in setPartialWindow() if x or w are not multiple of 8 for even rotation, y or h for odd rotation
// see also comment in GxEPD2_BW.h, GxEPD2_3C.h or GxEPD2_GFX.h for method setPartialWindow()
// showPartialUpdate() purposely uses values that are not multiples of 8 to test this

void showPartialUpdate()
{
  // some useful background
  helloWorld();
  // use asymmetric values for test
  uint16_t box_x = 10;
  uint16_t box_y = 15;
  uint16_t box_w = 70;
  uint16_t box_h = 20;
  uint16_t cursor_y = box_y + box_h - 6;
  if (display.epd2.WIDTH < 104) cursor_y = box_y + 6;
  float value = 13.95;
  uint16_t incr = display.epd2.hasFastPartialUpdate ? 1 : 3;
  display.setFont(&FreeMonoBold9pt7b);
  if (display.epd2.WIDTH < 104) display.setFont(0);
  display.setTextColor(GxEPD_BLACK);
  // show where the update box is
  for (uint16_t r = 0; r < 4; r++)
  {
    display.setRotation(r);
    display.setPartialWindow(box_x, box_y, box_w, box_h);
    display.firstPage();
    do
    {
      display.fillRect(box_x, box_y, box_w, box_h, GxEPD_BLACK);
      //display.fillScreen(GxEPD_BLACK);
    }
    while (display.nextPage());
    delay(2000);
    display.firstPage();
    do
    {
      display.fillRect(box_x, box_y, box_w, box_h, GxEPD_WHITE);
    }
    while (display.nextPage());
    delay(1000);
  }
  //return;
  // show updates in the update box
  for (uint16_t r = 0; r < 4; r++)
  {
    display.setRotation(r);
    display.setPartialWindow(box_x, box_y, box_w, box_h);
    for (uint16_t i = 1; i <= 10; i += incr)
    {
      display.firstPage();
      do
      {
        display.fillRect(box_x, box_y, box_w, box_h, GxEPD_WHITE);
        display.setCursor(box_x, cursor_y);
        display.print(value * i, 2);
      }
      while (display.nextPage());
      delay(500);
    }
    delay(1000);
    display.firstPage();
    do
    {
      display.fillRect(box_x, box_y, box_w, box_h, GxEPD_WHITE);
    }
    while (display.nextPage());
    delay(1000);
  }
}


void drawBitmaps()
{
  display.setFullWindow();
#ifdef _GxBitmaps80x128_H_
  drawBitmaps80x128();
#endif
#ifdef _GxBitmaps152x152_H_
  drawBitmaps152x152();
#endif
#ifdef _GxBitmaps104x212_H_
  drawBitmaps104x212();
#endif
#ifdef _GxBitmaps128x250_H_
  drawBitmaps128x250();
#endif
#ifdef _GxBitmaps128x296_H_
  drawBitmaps128x296();
#endif
#ifdef _GxBitmaps176x264_H_
  drawBitmaps176x264();
#endif
#ifdef _GxBitmaps400x300_H_
  drawBitmaps400x300();
#endif
#ifdef _GxBitmaps640x384_H_
  drawBitmaps640x384();
#endif
#ifdef _GxBitmaps648x480_H_
  drawBitmaps648x480();
#endif
#ifdef _GxBitmaps800x480_H_
  drawBitmaps800x480();
#endif
#ifdef _WS_Bitmaps800x600_H_
  drawBitmaps800x600();
#endif
#if defined(ESP32) && defined(_GxBitmaps1304x984_H_)
  drawBitmaps1304x984();
#endif
  // 3-color
#ifdef _GxBitmaps3c104x212_H_
  drawBitmaps3c104x212();
#endif
#ifdef _GxBitmaps3c128x250_H_
  drawBitmaps3c128x250();
#endif
#ifdef _GxBitmaps3c128x296_H_
  drawBitmaps3c128x296();
#endif
#ifdef _GxBitmaps152x296_H_
  drawBitmaps152x296();
#endif
#ifdef _GxBitmaps3c176x264_H_
  drawBitmaps3c176x264();
#endif
#ifdef _GxBitmaps240x416_H_
  drawBitmaps240x416();
#endif
#ifdef _GxBitmaps3c400x300_H_
  drawBitmaps3c400x300();
#endif
#ifdef _GxBitmaps3c800x480_H_
  drawBitmaps3c800x480();
#endif
#ifdef _GxBitmaps3c880x528_H_
  drawBitmaps3c880x528();
#endif
#if defined(_WS_Bitmaps7c192x143_H_)
  drawBitmaps7c192x143();
#endif
  if ((display.epd2.WIDTH >= 200) && (display.epd2.HEIGHT >= 200))
  {
    // show these after the specific bitmaps
#ifdef _GxBitmaps200x200_H_
    drawBitmaps200x200();
#endif
    // 3-color
#ifdef _GxBitmaps3c200x200_H_
    drawBitmaps3c200x200();
#endif
  }
}

#ifdef _GxBitmaps80x128_H_
void drawBitmaps80x128()
{
#if !defined(__AVR)
  const unsigned char* bitmaps[] =
  {
    Bitmap80x128_1, Bitmap80x128_2, Bitmap80x128_3, Bitmap80x128_4, Bitmap80x128_5
  };
#else
  const unsigned char* bitmaps[] =
  {
    Bitmap80x128_1, Bitmap80x128_2, Bitmap80x128_3, Bitmap80x128_4, Bitmap80x128_5
  };
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

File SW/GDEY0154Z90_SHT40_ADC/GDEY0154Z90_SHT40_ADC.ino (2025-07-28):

/* Example code shows values from SHT40 (temperature/humidity), battery voltage on eInk/ePaper display
 * example from libraries are used
 * 
 * Board:   LaskaKit microESPink ESP32-S3   https://www.laskakit.cz/laskakit-microespink-esp32-s3-mini-e-paper/
 * Display: Good Display GDEY0154Z90        https://www.laskakit.cz/good-display-gdey0154z90-1-54--200x200-cerveny-epaper-displej/
 * Sensor: SHT40                            https://www.laskakit.cz/laskakit-sht40-senzor-teploty-a-vlhkosti-vzduchu/ is connected through uSup connector 
 * 
 * Libraries:
 * SHT40: https://github.com/adafruit/Adafruit_SHT4X
 * EPD library: https://github.com/ZinggJM/GxEPD2
 *
 * Email:podpora@laskakit.cz
 * Web:laskakit.cz
 */
 
#include <WiFi.h>
#include <GxEPD2_BW.h>
#include <GxEPD2_3C.h>
#include <GxEPD2_4C.h>
#include "SPI.h"
#include "Adafruit_SHT4x.h"
#include "OpenSansSB_12px.h"
#include "OpenSansSB_50px.h"
 
//MOSI/SDI    11
//CLK/SCK     12
//SS/CS       10
#define DC    48 
#define RST   45  
#define BUSY  38 
#define POWER 47
#define SDA   42
#define SCL   2
#define BAT   9

GxEPD2_3C<GxEPD2_154_Z90c, GxEPD2_154_Z90c::HEIGHT> display(GxEPD2_154_Z90c(SS, DC, RST, BUSY)); // GDEH0154Z90 200x200, SSD1681

// SHT40
Adafruit_SHT4x sht4 = Adafruit_SHT4x();

// ADC
float vBat = 0.0;
 
void setup() {
  Serial.begin(115200);
  pinMode(POWER, OUTPUT); 
  digitalWrite(POWER, HIGH); // enable power supply for ePaper and uSup
  delay(500);

  // read ADC and calculate the voltage
  vBat = analogReadMilliVolts(BAT) * 1.769 / 1000; // the ratio of divider, R2=1.3M; R1=1M


  /*----------- SHT40 -----------*/
  Wire.begin(SDA,SCL);
  if (! sht4.begin()) 
  {
    Serial.println("SHT4x not found");
    Serial.println("Check connection");
    while (1) delay(1);
  }

  sht4.setPrecision(SHT4X_HIGH_PRECISION); // the higest resolution
  sht4.setHeater(SHT4X_NO_HEATER); // no heater

  sensors_event_t humidity, temperature; // variable for humidity and temperature
  sht4.getEvent(&humidity, &temperature); // read value

  Serial.print("Temperature: "); Serial.print(temperature.temperature); Serial.println(" degrees C");
  Serial.print("Humidity: "); Serial.print(humidity.relative_humidity); Serial.println("% rH");

  display.init(); // inicializace

  display.setRotation(3);
  display.fillScreen(GxEPD_WHITE);  // white background
  display.setTextColor(GxEPD_BLACK);  // black font

  display.setCursor(/*x*/5, /*y*/50); // set cursor
  display.setFont(&OpenSansSB_50px); // font
  display.print(String(temperature.temperature, 1)); 
  display.print("  ");
  display.print(String(humidity.relative_humidity, 0)); 

  display.setFont(&OpenSansSB_12px); // font
  display.setCursor(/*x*/30, /*y*/70); // set cursor
  display.println(" degC");
  display.setCursor(/*x*/150, /*y*/70); // set cursor
  display.println(" % Rh");

  display.setCursor(/*x*/160, /*y*/100); // set cursor
  display.print(vBat);
  display.print(" V");

  display.display(false); // update 
  delay(100);
  digitalWrite(POWER, LOW); // disable power supply for ePaper

  // deep sleep mode
  esp_sleep_enable_timer_wakeup(300 * 1000000);
  delay(200);
  esp_deep_sleep_start();
}

void loop() {}

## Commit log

2025-03-13 new test data
    [microESPink_v1_1_bottom_bom.csv, microESPink_v1_1_top_bom.csv, microESPink_v1_bom.csv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]
2025-07-28 new ver data
    [microESPink_v1_2_bom.csv]
2025-10-27 new ver
    [microESPink_v1_2_bom.csv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]
2026-10-29 Fix typo in device identifier GDEYO29F51H
